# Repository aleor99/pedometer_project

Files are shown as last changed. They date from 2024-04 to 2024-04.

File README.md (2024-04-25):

# **FINAL ASSIGNMENT**

## **Electronic Technologies and Sensors Laboratory (Prof. Cerveri Pietro)**

**Students**:

Simone Lambiase

Miriam Morelli

Alessandro Ortu

**Tutor**:
Luca Marsilio

### **Description**

In this project, we designed and developed a wearable system that measures physical activity parameters from the 3-axis accelerometer LIS3DH.

The main objectives of this system are:

- Acquire data from the accelerometer using built-in FIFO to reduce the load of the CPU.
- Process and calibrate the raw data in order to obtain steps, calories, distance and speed.
- Provide a Graphical-User-Interface (GUI) where data can be displayed in real-time.
- Add some features to GUI and Hardware in order to make it more interactive and customizable.

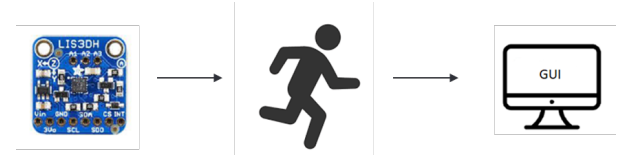
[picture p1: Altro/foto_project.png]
Semplice schematico del funzionamento


### **Requirements**

**Version**: *PSoC Creator 4.4*

**Board**: *PSoC 5LP CY8C5888LTI-LP097 in QFN68 format* [PSoC Creator](https://www.infineon.com/cms/en/design-support/tools/sdk/psoc-software/psoc-creator/)

**Additional Hardware**:

1. LIS3DH breakout board [LIS3DH Datasheet](https://www.st.com/resource/en/datasheet/lis3dh.pdf)
1. Bluetooth HC-06 [HC-06 Datasheet](https://www.st.com/resource/en/datasheet/lis3dh.pdf)
1. SSD1306 OLED by Adafruit [Adafruit Oled](https://www.adafruit.com/product/326)
1. Two external LEDs (Red and Green)
1. Button (Reset)
1. One LM7805 and two Capacitors in order to reduce the voltage from a 9 V battery to 5 V
1. One 9V battery
1. Three Resistors (two for the leds and one for the button)
2. Switch (ON/OFF)

(as an alternative to steps 6,7 and 9 , a powerbank can be used)

Additional softwares tools: Cool Term, Bridge Control Panel

## **Hardware**
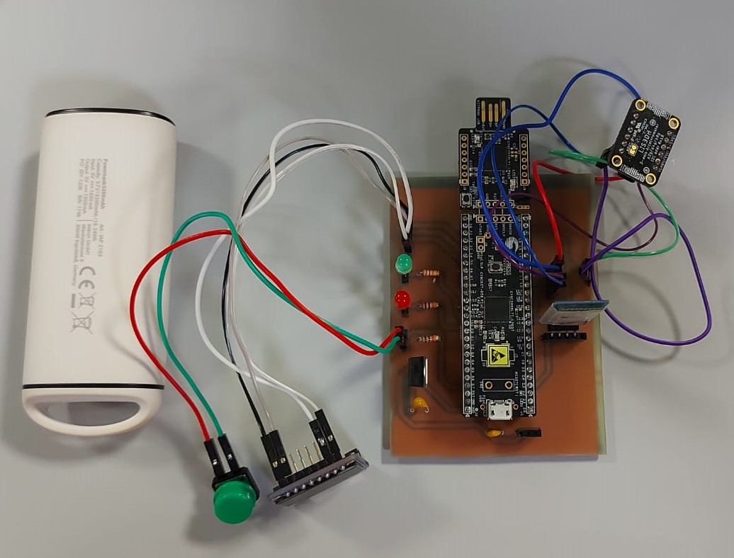
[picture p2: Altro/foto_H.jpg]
Foto Hardware

## **System Configuration**
Switch on the device via the switch (or alternatively connect the powerbank to the PSoC), check that the OLED turns on and that the Bluetooth starts flashing rapidly indicating that the device is ready to be connected. Connect the device to the PC via Bluetooth by selecting the HC-06 device and entering the password 1234. Once connected open the interface and follow the following steps:
1. Select your profile by going to "User Page", in the upper bar where you find "Search User" select your first and last name, click Load and then Save. Alternatively, register via the "Click here to register" button and then click "Save".
2. Select "Data Analysis", on this page you can view the data from the PSoC. Click "Search" and wait for the green text saying "Device found" to appear, then click "Run" to start the monitoring activity. At the bottom you will be able to see information about your physical activity, which are also shown on the OLED mounted on the device (you can switch from a parameter to the other by pressing the button on the device). At the end of monitoring, click the "Disconnect" button to disconnect.
3. In order to view and manage your data, go to "Database", on this page you can search for a user by name and by double-clicking on a row in the table, you will be able to see graphs of activity trends over time. You can also export your data to a .csv file by clicking on "Export Data".

***Additional Features***

There are two additional buttons:
- *Question mark button*: this page allows you to request help in using the interface or report possible errors. All required information must be entered and then click Send Request. 
- *Info Button*: this page shows information about the project and is the homepage of the GUI.

All operations performed on the GUI will be accompanied by warnings confirming the operation performed or helping to perform the desired operation. It is also possible to reduce the sidebar by clicking on the three lines on the left-hand side of the top bar.

### **Repository Organisation**
In the GUI FINALE folder you can find all the files necessary for the GUI, in particular:
- "Interfaccia_finale": contains the core code relating to the operation of the interface.
- "database_conn": contains the functions for connecting to the database via sqlite3.
- "dati_utenti.db": is the database (you can use DB Browser(SQLite) to open it).
- "icone_rc": contains the icons used in the interface.
- "nuova.ui": file containing the interface graphics.
- "costanti": a separate file with all the constants used.

In the PSOC folder there are all files pertaining to the PSoC firmware (divided in 2 versions, one where only the steps are shown on the OLED, the other with all the parameters, both working) and in the PC finale folder all files pertaining to the PCB.
Also, the case folder is divided in 2 folders: one for the case with the battery and one for the case with the powerbank.
Finally, in the "Altro" folder there are some old codes if you find them useful.

### **References**
- [PubMed link 1](https://pubmed.ncbi.nlm.nih.gov/25749552/)
- [PubMed link 2](https://pubmed.ncbi.nlm.nih.gov/24656871/)
- [Paper by Neil Zhao](https://www.analog.com/media/en/technical-documentation/technical-articles/pedometer.pdf)
- Course Notes by Pietro Cerveri

### **Final Presentation**
Link to the powerpoint final presentation and the videos of the demo: https://polimi365-my.sharepoint.com/:f:/g/personal/10675266_polimi_it/Ek28DVU131dCtsj3aeqviJQB96iRDbKKIaKprMv0jeDfnw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

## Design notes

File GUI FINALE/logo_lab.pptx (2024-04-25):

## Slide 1

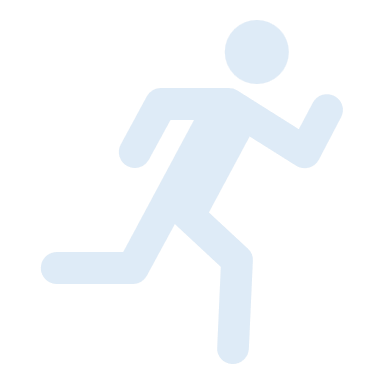
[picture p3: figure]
Eseguire con riempimento a tinta unita

Runner

Monitor, Measure, Improve

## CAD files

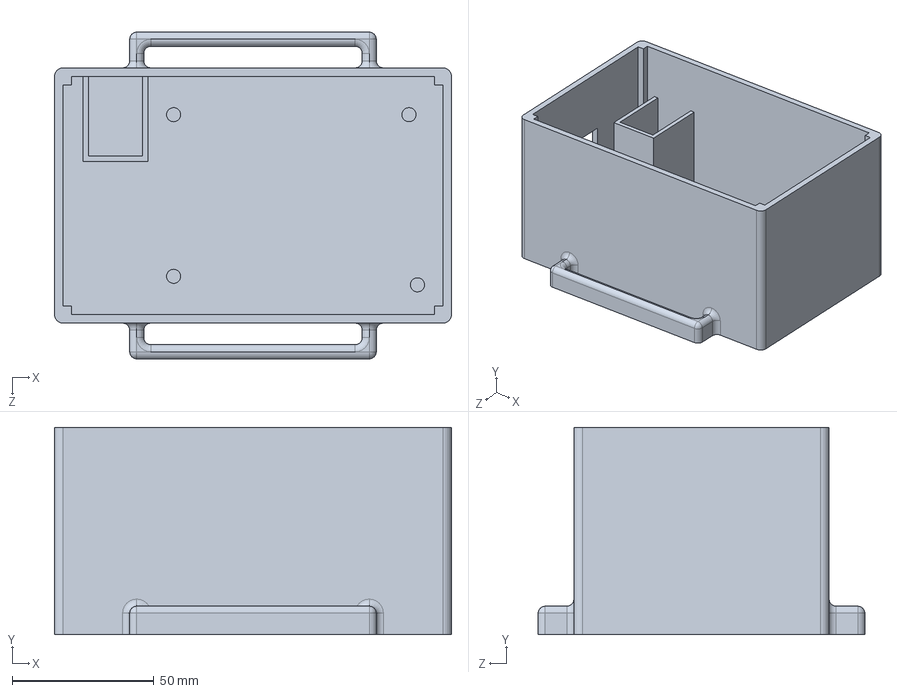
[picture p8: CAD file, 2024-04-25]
Case/Case_Batteria/Case_Batteria.SLDPRT
140.0 x 73.0 x 115.2 mm

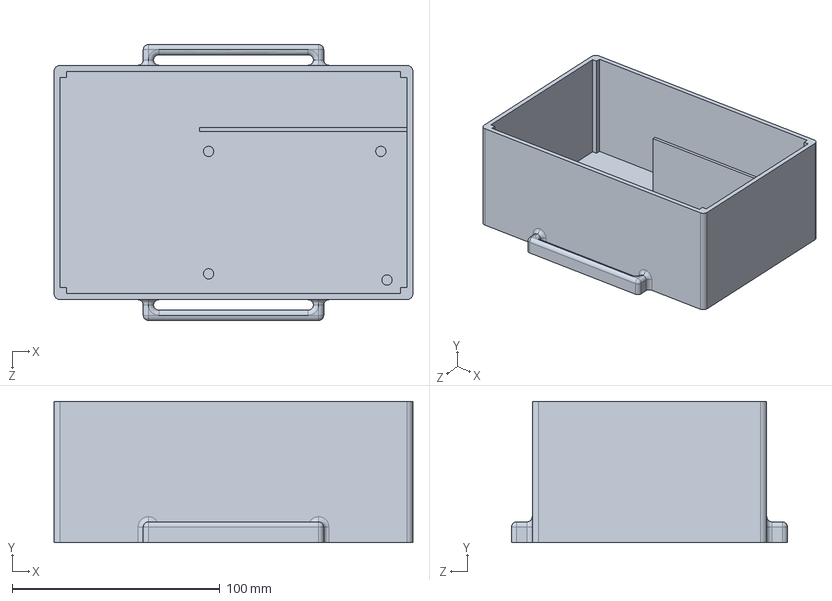
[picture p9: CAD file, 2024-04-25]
Case/Case_Powerbank/Case_Powerbank.SLDPRT
173.0 x 68.0 x 133.0 mm

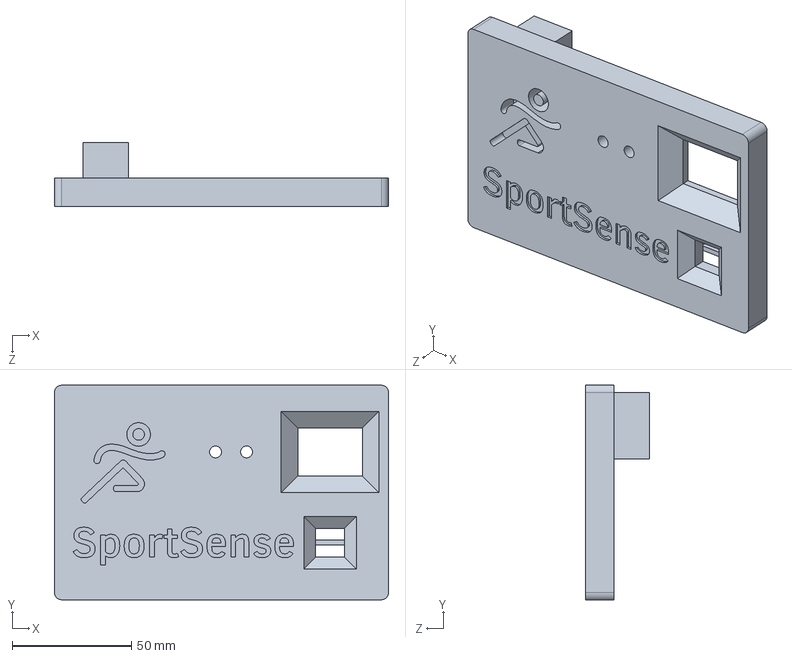
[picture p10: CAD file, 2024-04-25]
Case/Case_Batteria/Coperchio_Batteria.SLDPRT
140.0 x 90.0 x 27.0 mm

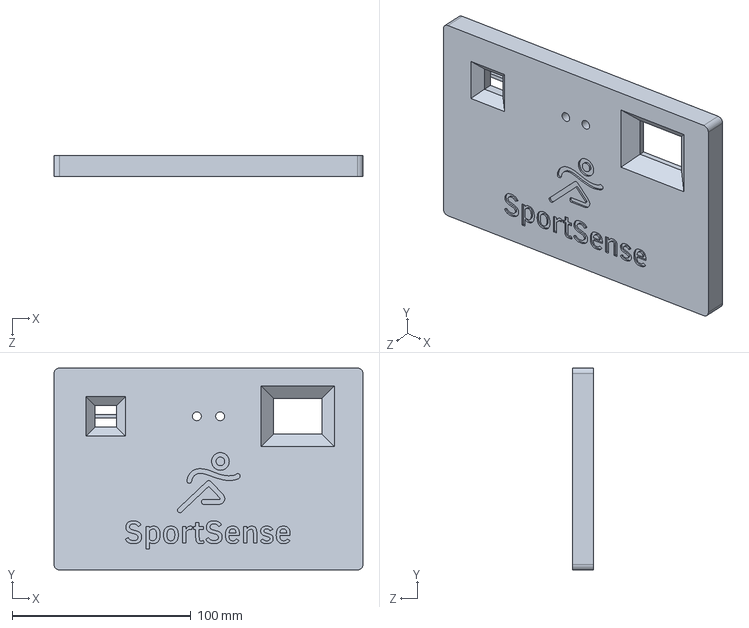
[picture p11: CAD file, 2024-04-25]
Case/Case_Powerbank/Coperchio_Powerbank.SLDPRT
173.0 x 113.0 x 12.0 mm

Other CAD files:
Case/Case_Batteria/Case_Batteria.STL
Case/Case_Batteria/Coperchio_Batteria.STL
Case/Case_Powerbank/Case_Powerbank.STL
Case/Case_Powerbank/Coperchio_Powerbank.STL

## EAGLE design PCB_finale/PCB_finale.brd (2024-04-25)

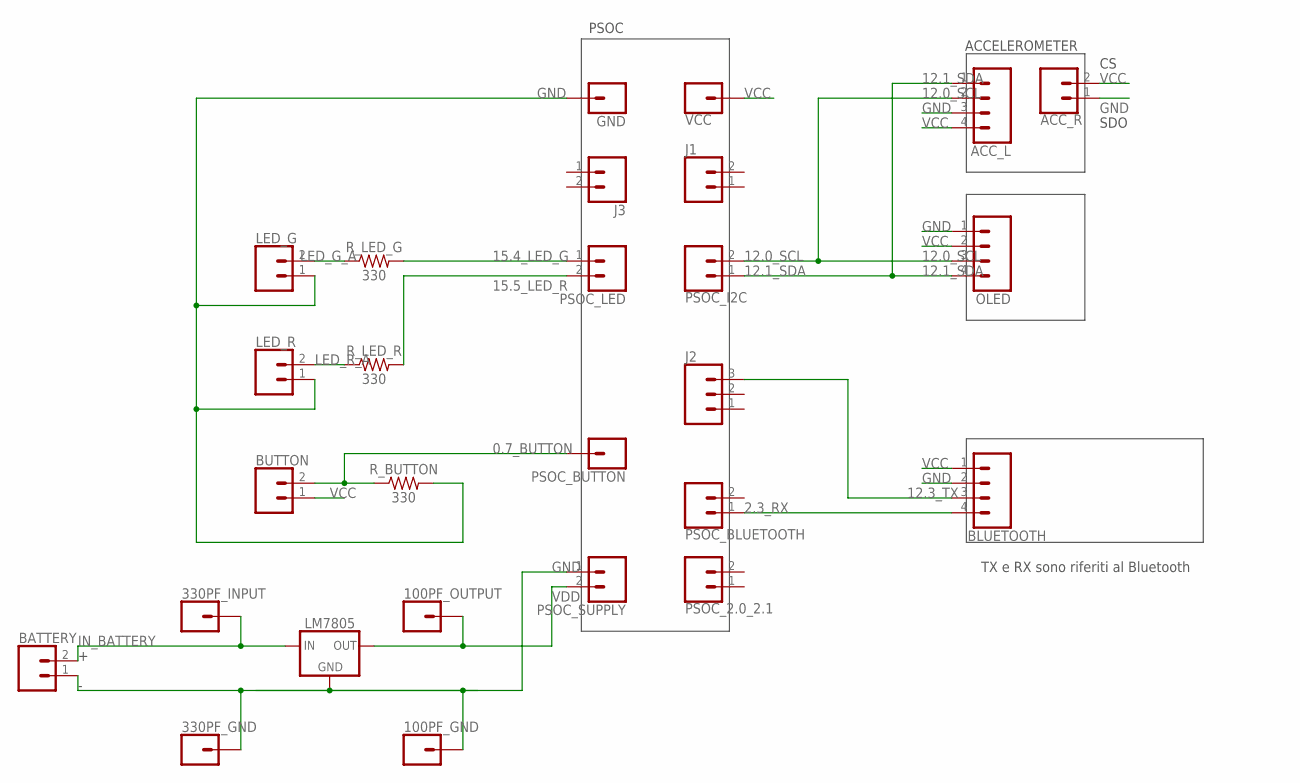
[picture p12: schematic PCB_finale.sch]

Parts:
100PF_GND, 100PF_OUTPUT, 330PF_GND, 330PF_INPUT: CONN_01; 1X01
ACC_L: CONN_04PTH; 1X04
ACC_R: CONN_02; 1X02
BATTERY: CONN_02; 1X02
BLUETOOTH: CONN_04PTH; 1X04
BUTTON: CONN_02; 1X02
GND: CONN_01; 1X01
J1, J3: CONN_02; 1X02
J2: 455-1750-1-ND; 1X03
LED_G: CONN_02; 1X02
LED_R: CONN_02; 1X02
LM7805: R-78E5.0-1.0; DC-DC_CONVERTER_78XX
OLED: CONN_04PTH; 1X04
PSOC_2.0_2.1: CONN_02; 1X02
PSOC_BLUETOOTH: CONN_02; 1X02
PSOC_BUTTON: CONN_01; 1X01
PSOC_I2C: CONN_02; 1X02
PSOC_LED: CONN_02; 1X02
PSOC_SUPPLY: CONN_02; 1X02
R_BUTTON: 330; AXIAL-0.3
R_LED_G: 330; AXIAL-0.3
R_LED_R: 330; AXIAL-0.3
VCC: CONN_01; 1X01

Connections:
0.7_BUTTON: BUTTON.2, PSOC_BUTTON.1, R_BUTTON.P$1 (1)
2.3_RX: BLUETOOTH.4, PSOC_BLUETOOTH.1
12.0_SCL: ACC_L.2, OLED.3, PSOC_I2C.2
12.1_SDA: ACC_L.1, OLED.4, PSOC_I2C.1
12.3_TX: BLUETOOTH.3, J2.3
15.4_LED_G: PSOC_LED.1, R_LED_G.P$2 (2)
15.5_LED_R: PSOC_LED.2, R_LED_R.P$2 (2)
GND: 100PF_GND.1, 330PF_GND.1, ACC_L.3, ACC_R.1, BATTERY.1, BLUETOOTH.2, GND.1, LED_G.1, LED_R.1, LM7805.GND, OLED.1, PSOC_SUPPLY.1, R_BUTTON.P$2 (2)
IN_BATTERY: 330PF_INPUT.1, BATTERY.2, LM7805.VIN (IN)
LED_G_A: LED_G.2, R_LED_G.P$1 (1)
LED_R_A: LED_R.2, R_LED_R.P$1 (1)
VCC: ACC_L.4, ACC_R.2, BLUETOOTH.1, BUTTON.1, OLED.2, VCC.1
VDD: 100PF_OUTPUT.1, LM7805.VOUT (OUT), PSOC_SUPPLY.2

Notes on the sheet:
PSOC
ACCELEROMETER
SDO
TX e RX sono riferiti al Bluetooth

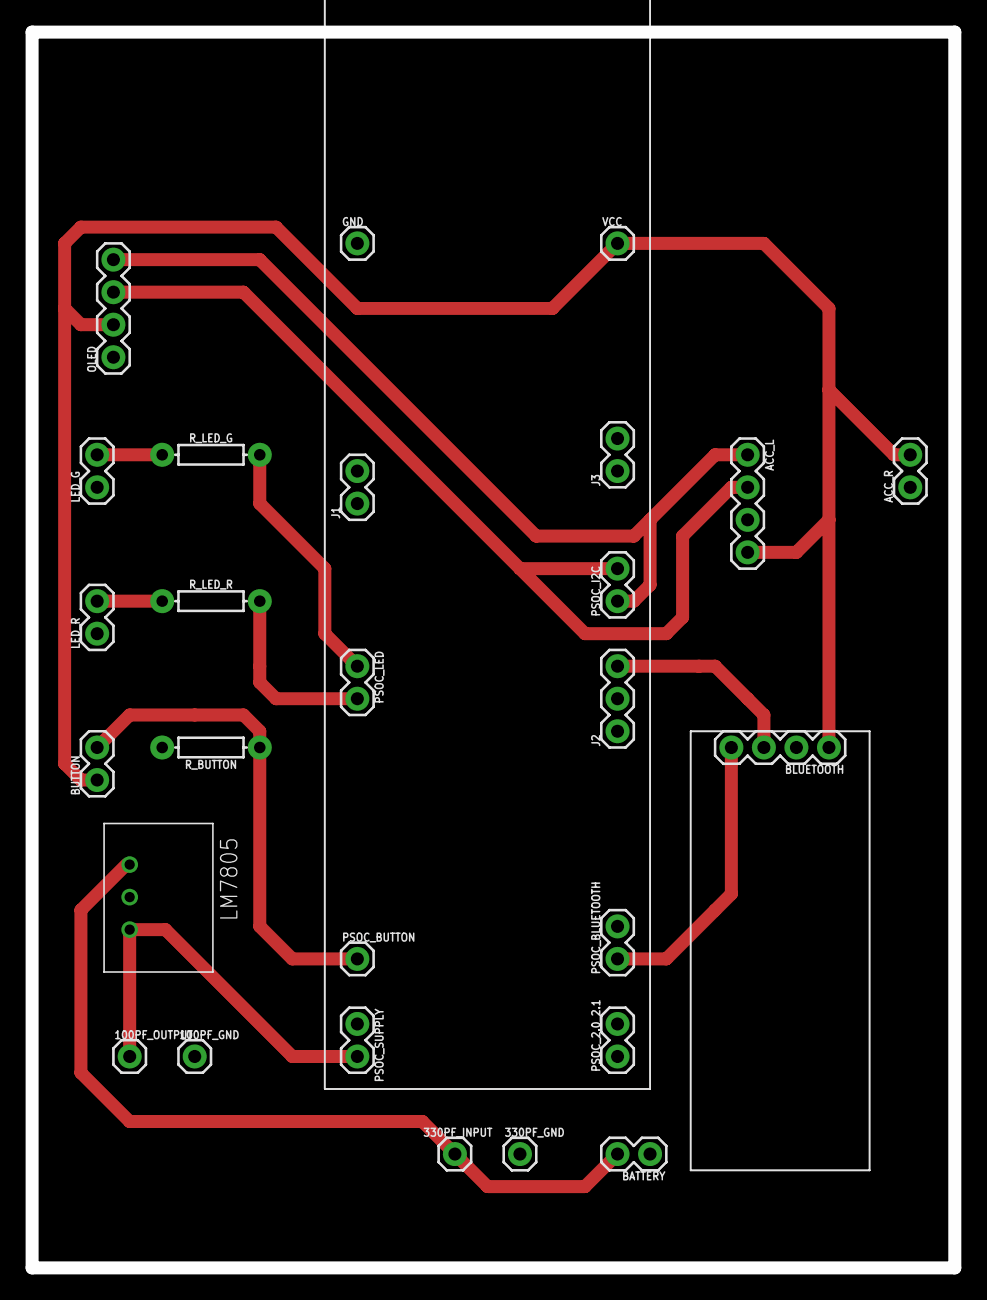
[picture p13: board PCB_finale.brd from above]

Board: 2 copper layers, 72.1 x 96.5 mm, 27 parts (0 on the bottom side), 13 nets.

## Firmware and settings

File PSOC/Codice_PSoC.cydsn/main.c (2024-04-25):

/* ========================================
 *
 * Copyright YOUR COMPANY, THE YEAR
 * All Rights Reserved
 * UNPUBLISHED, LICENSED SOFTWARE.
 *
 * CONFIDENTIAL AND PROPRIETARY INFORMATION
 * WHICH IS THE PROPERTY OF your company.
 *
 * ========================================
*/

//** libraries **//
#include <stdio.h>
#include "project.h"
#include "I2C_Interface.h"
#include "LIS3DH.h"
#include "InterruptRoutines.h"
#include "isr_RX.h"
#include "ssd1306.h"
#include "logo.h"
#include <stdlib.h>

//** define **//
#define ON 1
#define OFF 0   //controllare se li usiamo 
#define DISPLAY_ADDRESS 0x3D
#define DISPLAYWIDTH 128
#define DISPLAYHEIGHT 64

char message[50] = {'\0'};
char cal[3] ="cal";
char metri[5]=" m";
char ms[4]=" m/s";
int agg=11;
char acapo[2]="\n";


int main(void)
{
    CyGlobalIntEnable; /* Enable global interrupts. */
    
    //**Inizializations**//
    I2C_Peripheral_Start();
    display_init(DISPLAY_ADDRESS);
    UART_1_Start();
    PWM_LED_ACC_Start();
    
    //**Power up graphics**// 
    int16_t j;
    for( j = 0 ; j < gfx_height() ; j += 2 ){
            gfx_drawCircle( gfx_width()/2, gfx_height()/2, j, WHITE );
            display_update();    
        }    

    CyDelay(3000);
    
    display_clear();    
    display_update(); 
    
    CyDelay(5);
    display_clear();    
    display_update();    
    gfx_setTextSize(2);
    gfx_setTextColor(WHITE);
    gfx_setCursor(2,2);
    gfx_println("Hey there!");
    display_update();


    
    
    //**Check if LIS3DH is connected**//    
    uint32_t rval = I2C_Master_MasterSendStart(LIS3DH_DEVICE_ADDRESS, I2C_Master_WRITE_XFER_MODE);
    if( rval == I2C_Master_MSTR_NO_ERROR ) {
    }
    I2C_Master_MasterSendStop();
    
  
	//UART_1_PutString("\n\n");
    
    /******************************************/
    /*            I2C Reading                 */
    /******************************************/
          
    //**I2C Master Read - WHOAMI Register **//
    uint8_t whoami_reg;
    ErrorCode error = I2C_Peripheral_ReadRegister(LIS3DH_DEVICE_ADDRESS, 
                                                  LIS3DH_WHO_AM_I_REG_ADDR,
                                                  &whoami_reg);
    if( error == ERROR ) {
        Pin_LED_CMT_Write(ON);
    }
    //if the comunication is not correct, so if the accelerometer register is not red correctly 
    //the LED is switched on 
        

    
    //**I2C Master Read - CTRL Register 1 **//
        
    /*       control_reg1: 0x47           */
    /*         ODR[3:0]-->0100            */
    /*      LPen-->DefaultValue:0         */
    /*   Zen,Yen,Xen-->DefaultValue:1     */
    
    
    uint8_t control_reg;
    error = I2C_Peripheral_ReadRegister(LIS3DH_DEVICE_ADDRESS, 
                                        LIS3DH_CTRL_REG1,
                                        &control_reg);
    control_reg |= 0x47; // sampling 50Hz
    error = I2C_Peripheral_WriteRegister(LIS3DH_DEVICE_ADDRESS,
                                         LIS3DH_CTRL_REG1,
                                         control_reg);                  
    
    //*   I2C Temperature CTRL REG 4 Writing from LIS3DH   **//
    /*       control_reg2: 0x80               */
    /*              BDU-->1                   */
    /*        BLE-->DefaultValue:0            */
    /*       FS-->DefaultValue:00             */
    /*        HR-->DefaultValue:0             */
    /*      ST[1:0]-->DefaultValue:00         */
    /*        SIM-->DefaultValue:0            */
    
    uint8_t ctrl_reg4; // Ctrl Register variable
    error = I2C_Peripheral_ReadRegister(LIS3DH_DEVICE_ADDRESS,
                                        LIS3DH_CTRL_REG4,
                                        &ctrl_reg4);
    
    ctrl_reg4 |= LIS3DH_CTRL_REG4_BDU_ACTIVE; // must be changed to the appropriate value
    error = I2C_Peripheral_WriteRegister(LIS3DH_DEVICE_ADDRESS,
                                         LIS3DH_CTRL_REG4,
                                         ctrl_reg4);
    //* SETTING DEL FIFO *//
    
    /////////* ctrl_reg5: 0x40 */////////
    /*   BOOT --> Default value:0      */
    /*   FIFO_EN --> 1                 */
    /*   LIR_INT1 --> Default value: 0 */
    /*   D4D_INT1 --> Default value: 0 */
    /*   LIR_INT2 --> Default value: 0 */
    /*   D4D_INT2 --> Default value: 0 */
    
    uint8_t ctrl_reg5; // Ctrl Register variable
    
    error = I2C_Peripheral_ReadRegister(LIS3DH_DEVICE_ADDRESS,
                                        LIS3DH_CTRL_REG5,
                                        &ctrl_reg5);
    ctrl_reg5 |= 0x40; // enable del FIFO
    error = I2C_Peripheral_WriteRegister(LIS3DH_DEVICE_ADDRESS,
                                         LIS3DH_CTRL_REG5,
                                         ctrl_reg5); 
    
    
    //* FIFO_CTRL_REG: 0x40 *//
        
    /*      FM[1:0] --> 01 (FIFO mode)     */
    /*       TR --> Default value: 0       */
    /*   FTH[4:0] --> Default value: 0000  */
    
    uint8_t FIFO_ctrl_reg;
    
    error = I2C_Peripheral_ReadRegister(LIS3DH_DEVICE_ADDRESS,
                                        LIS3DH_FIFO_CTRL_REG,
                                        &FIFO_ctrl_reg);
    
    FIFO_ctrl_reg |= 0x40; //FIFO mode (FM = 01)
    error = I2C_Peripheral_WriteRegister(LIS3DH_DEVICE_ADDRESS,
                                         LIS3DH_FIFO_CTRL_REG,
                                         FIFO_ctrl_reg); 
    
        
    //Accelerations
    uint8_t AccData[2]; //for the two register in which are contained the 10 bits 
    int16_t OutAcc;
    
    uint8_t FIFO_src_reg; 
    uint8_t FIFO_overrun; 
    //uint8_t FIFO_unread_samples;
    
    uint8_t i=0;
    uint8_t accelerazioni_multi[192];
    uint8_t flag_ci=OFF;

    
    //**Starting of interrupts**//
    isr_RX_StartEx(Custom_ISR_RX);
    isr_BUTTON_StartEx(Custom_ISR_BUTTON);
    isr_Timer_StartEx(Custom_ISR_Timer);
    Timer_Start();
    
    for(;;)
    {
        if(Connessione_porta)
        {
            sprintf(message, "h ");
            UART_1_PutString(message);
            Connessione_porta=0;        
        }
        //When, from the GUI, the signal arrives to start the data reading 
        if (Invio_dati)
        {
            //Check FIFO overrun --> once is full teh reading starts
            error = I2C_Peripheral_ReadRegister(LIS3DH_DEVICE_ADDRESS,
                                                  LIS3DH_FIFO_SRC_REG,
                                                    &FIFO_src_reg);
            if((error!=NO_ERROR)&(flag_ci==OFF))
            {
                    Pin_LED_CMT_Write(ON);                   
                    flag_ci=ON;        
            }
            else if(error==NO_ERROR)
            {
                FIFO_overrun = FIFO_src_reg & 0x40; 
                if(FIFO_overrun == 0x40)
                {
                    flag_ci=OFF;                    
                    Pin_LED_CMT_Write(OFF);                    
                    //Reading of the data 
                    error = I2C_Peripheral_ReadRegisterMulti(LIS3DH_DEVICE_ADDRESS,
                                                             LIS3DH_OUT_ACCX_L,
                                                             192,
                                                             accelerazioni_multi);

                    //Single accelerations' computation
                    for(i=0; i<32; i++)
                    {
                        if(error == NO_ERROR)
                        {
                            //Acceleration along x axis: positions  0-1, 6-7, 12-13, ...
                            AccData[0]=accelerazioni_multi[6*i];   
                            AccData[1]=accelerazioni_multi[6*i+1];
                            OutAcc = (int16) (AccData[0] | (AccData[1] << 8)) >> 6;
                            OutAcc=(OutAcc*4);
                            sprintf(message, "Accx Output: %d mg\r\n", OutAcc);
                            UART_1_PutString(message);
                            
                            //Acceleration along y axis: positions 2-3, 8-9, 14-15, ...
                            AccData[0]=accelerazioni_multi[6*i+2];
                            AccData[1]=accelerazioni_multi[6*i+3];
                            OutAcc = (int16) (AccData[0] | (AccData[1] << 8)) >> 6;
                            OutAcc=(OutAcc*4);
                            sprintf(message, "Accy Output: %d mg \r\n", OutAcc);
                            UART_1_PutString(message);
                            
                            //Acceleration along z axis: positions 4-5, 10-11, 16-17, ...
                            AccData[0]=accelerazioni_multi[6*i+4];
                            AccData[1]=accelerazioni_multi[6*i+5];
                            OutAcc = (int16) (AccData[0] | (AccData[1] << 8)) >> 6;
                            OutAcc=(OutAcc*4);
                            sprintf(message, "Accz Output: %d mg\r\n", OutAcc);
                            UART_1_PutString(message);                            
                        }
                    }
                    
                    //FIFO's reset
                    FIFO_ctrl_reg &= 0x00; //Bypass mode
                    error = I2C_Peripheral_WriteRegister(LIS3DH_DEVICE_ADDRESS,
                                                         LIS3DH_FIFO_CTRL_REG,
                                                         FIFO_ctrl_reg); 
                    CyDelay(100);
                    
                    FIFO_ctrl_reg |= 0x40; //FIFO mode (FM = 01)
                    error = I2C_Peripheral_WriteRegister(LIS3DH_DEVICE_ADDRESS,
                                                         LIS3DH_FIFO_CTRL_REG,
                                                         FIFO_ctrl_reg);   
                    CyDelay(50);
                    
                    if(backup_s==ON)//print of the steps, made in the main for the interference between 
                                    //OLED and accelerometer                    
                    {
                        sprintf(message,"Steps: %lu",steps);
                        display_clear();    
                        display_update();    
                        gfx_setTextSize(2);
                        gfx_setTextColor(WHITE);
                        gfx_setCursor(2,2);
                        gfx_print(message);
                        display_update();  
                    }              
                    if (backup_v==ON)
                    {        
                        if(invio_OLED)
                        {
                          velocity[0]='\n';       
                          char vel_cor[BUFFER_SIZE]="Velocity: \n";
                          strcat(vel_cor,acapo);
                          for(uint i=0; i<strlen(velocity);i++)
                          {
                             if ((velocity[i]=='1') || (velocity[i]=='2')|| (velocity[i]=='3')|| (velocity[i]=='4')|| (velocity[i]=='5')|| (velocity[i]=='6')|| (velocity[i]=='7')|| (velocity[i]=='8')|| (velocity[i]=='9')|| (velocity[i]=='0'))
                            {
                                vel_cor[agg++]=velocity[i];
                            }
                          }
                          agg=11;
                          strcat(vel_cor,ms);
                          display_clear();    
                          display_update();    
                          gfx_setTextSize(2);
                          gfx_setTextColor(WHITE);
                          gfx_setCursor(2,2);
                          gfx_println(vel_cor);
                          display_update();   
                          flag_v=OFF;
                          invio_OLED=OFF;
                        }
                    }
                    if (backup_d==ON)
                    {        
                        if(invio_OLED)
                        {
                          distance[0]='\n';       
                          char dis_cor[BUFFER_SIZE]="Distance: \n";
                          strcat(dis_cor,acapo);
                          for(uint i=0; i<strlen(distance);i++)
                          {
                             if ((distance[i]=='1') || (distance[i]=='2')|| (distance[i]=='3')|| (distance[i]=='4')|| (distance[i]=='5')|| (distance[i]=='6')|| (distance[i]=='7')|| (distance[i]=='8')|| (distance[i]=='9')|| (distance[i]=='0'))
                            {
                                dis_cor[agg++]=distance[i];
                            }
                          }
                          agg=11;
                          strcat(dis_cor,metri);
                          display_clear();    
                          display_update();    
                          gfx_setTextSize(2);
                          gfx_setTextColor(WHITE);
                          gfx_setCursor(2,2);
                          gfx_println(dis_cor);
                          display_update();   
                          flag_d=OFF;
                          invio_OLED=OFF;
                        }
                    }
                    if (backup_k==ON)
                    {        
                        if(invio_OLED)
                        {
                          calories[0]='\n';       
                          char cal_cor[BUFFER_SIZE]="Calories: \n";
                          strcat(cal_cor,acapo);
                          for(uint i=0; i<strlen(calories);i++)
                          {
                             if ((calories[i]=='1') || (calories[i]=='2')|| (calories[i]=='3')|| (calories[i]=='4')|| (calories[i]=='5')|| (calories[i]=='6')|| (calories[i]=='7')|| (calories[i]=='8')|| (calories[i]=='9')|| (calories[i]=='0'))
                            {
                                cal_cor[agg++]=calories[i];
                            }
                          }  
                          agg=11; 
                          strcat(cal_cor,cal);
                          display_clear();    
                          display_update();    
                          gfx_setTextSize(2);
                          gfx_setTextColor(WHITE);
                          gfx_setCursor(2,2);
                          gfx_println(cal_cor);
                          display_update();   
                          flag_k=OFF;
                          invio_OLED=OFF;
                        }
                    }
                }
            }
        }
    }
}
/* [] END OF FILE */

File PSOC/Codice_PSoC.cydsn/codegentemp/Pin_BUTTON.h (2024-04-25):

/*******************************************************************************
* File Name: Pin_BUTTON.h  
* Version 2.20
*
* Description:
*  This file contains Pin function prototypes and register defines
*
* Note:
*
********************************************************************************
* Copyright 2008-2015, Cypress Semiconductor Corporation.  All rights reserved.
* You may use this file only in accordance with the license, terms, conditions, 
* disclaimers, and limitations in the end user license agreement accompanying 
* the software package with which this file was provided.
*******************************************************************************/

#if !defined(CY_PINS_Pin_BUTTON_H) /* Pins Pin_BUTTON_H */
#define CY_PINS_Pin_BUTTON_H

#include "cytypes.h"
#include "cyfitter.h"
#include "cypins.h"
#include "Pin_BUTTON_aliases.h"

/* APIs are not generated for P15[7:6] */
#if !(CY_PSOC5A &&\
	 Pin_BUTTON__PORT == 15 && ((Pin_BUTTON__MASK & 0xC0) != 0))


/***************************************
*        Function Prototypes             
***************************************/    

/**
* \addtogroup group_general
* @{
*/
void    Pin_BUTTON_Write(uint8 value);
void    Pin_BUTTON_SetDriveMode(uint8 mode);
uint8   Pin_BUTTON_ReadDataReg(void);
uint8   Pin_BUTTON_Read(void);
void    Pin_BUTTON_SetInterruptMode(uint16 position, uint16 mode);
uint8   Pin_BUTTON_ClearInterrupt(void);
/** @} general */

/***************************************
*           API Constants        
***************************************/
/**
* \addtogroup group_constants
* @{
*/
    /** \addtogroup driveMode Drive mode constants
     * \brief Constants to be passed as "mode" parameter in the Pin_BUTTON_SetDriveMode() function.
     *  @{
     */
        #define Pin_BUTTON_DM_ALG_HIZ         PIN_DM_ALG_HIZ
        #define Pin_BUTTON_DM_DIG_HIZ         PIN_DM_DIG_HIZ
        #define Pin_BUTTON_DM_RES_UP          PIN_DM_RES_UP
        #define Pin_BUTTON_DM_RES_DWN         PIN_DM_RES_DWN
        #define Pin_BUTTON_DM_OD_LO           PIN_DM_OD_LO
        #define Pin_BUTTON_DM_OD_HI           PIN_DM_OD_HI
        #define Pin_BUTTON_DM_STRONG          PIN_DM_STRONG
        #define Pin_BUTTON_DM_RES_UPDWN       PIN_DM_RES_UPDWN
    /** @} driveMode */
/** @} group_constants */
    
/* Digital Port Constants */
#define Pin_BUTTON_MASK               Pin_BUTTON__MASK
#define Pin_BUTTON_SHIFT              Pin_BUTTON__SHIFT
#define Pin_BUTTON_WIDTH              1u

/* Interrupt constants */
#if defined(Pin_BUTTON__INTSTAT)
/**
* \addtogroup group_constants
* @{
*/
    /** \addtogroup intrMode Interrupt constants
     * \brief Constants to be passed as "mode" parameter in Pin_BUTTON_SetInterruptMode() function.
     *  @{
     */
        #define Pin_BUTTON_INTR_NONE      (uint16)(0x0000u)
        #define Pin_BUTTON_INTR_RISING    (uint16)(0x0001u)
        #define Pin_BUTTON_INTR_FALLING   (uint16)(0x0002u)
        #define Pin_BUTTON_INTR_BOTH      (uint16)(0x0003u) 
    /** @} intrMode */
/** @} group_constants */

    #define Pin_BUTTON_INTR_MASK      (0x01u) 
#endif /* (Pin_BUTTON__INTSTAT) */


/***************************************
*             Registers        
***************************************/

/* Main Port Registers */
/* Pin State */
#define Pin_BUTTON_PS                     (* (reg8 *) Pin_BUTTON__PS)
/* Data Register */
#define Pin_BUTTON_DR                     (* (reg8 *) Pin_BUTTON__DR)
/* Port Number */
#define Pin_BUTTON_PRT_NUM                (* (reg8 *) Pin_BUTTON__PRT) 
/* Connect to Analog Globals */                                                  
#define Pin_BUTTON_AG                     (* (reg8 *) Pin_BUTTON__AG)                       
/* Analog MUX bux enable */
#define Pin_BUTTON_AMUX                   (* (reg8 *) Pin_BUTTON__AMUX) 
/* Bidirectional Enable */                                                        
#define Pin_BUTTON_BIE                    (* (reg8 *) Pin_BUTTON__BIE)
/* Bit-mask for Aliased Register Access */
#define Pin_BUTTON_BIT_MASK               (* (reg8 *) Pin_BUTTON__BIT_MASK)
/* Bypass Enable */
#define Pin_BUTTON_BYP                    (* (reg8 *) Pin_BUTTON__BYP)
/* Port wide control signals */                                                   
#define Pin_BUTTON_CTL                    (* (reg8 *) Pin_BUTTON__CTL)
/* Drive Modes */
#define Pin_BUTTON_DM0                    (* (reg8 *) Pin_BUTTON__DM0) 
#define Pin_BUTTON_DM1                    (* (reg8 *) Pin_BUTTON__DM1)
#define Pin_BUTTON_DM2                    (* (reg8 *) Pin_BUTTON__DM2) 
/* Input Buffer Disable Override */
#define Pin_BUTTON_INP_DIS                (* (reg8 *) Pin_BUTTON__INP_DIS)
/* LCD Common or Segment Drive */
#define Pin_BUTTON_LCD_COM_SEG            (* (reg8 *) Pin_BUTTON__LCD_COM_SEG)
/* Enable Segment LCD */
#define Pin_BUTTON_LCD_EN                 (* (reg8 *) Pin_BUTTON__LCD_EN)
/* Slew Rate Control */
#define Pin_BUTTON_SLW                    (* (reg8 *) Pin_BUTTON__SLW)
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

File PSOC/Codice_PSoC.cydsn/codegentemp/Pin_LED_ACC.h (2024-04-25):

/*******************************************************************************
* File Name: Pin_LED_ACC.h  
* Version 2.20
*
* Description:
*  This file contains Pin function prototypes and register defines
*
* Note:
*
********************************************************************************
* Copyright 2008-2015, Cypress Semiconductor Corporation.  All rights reserved.
* You may use this file only in accordance with the license, terms, conditions, 
* disclaimers, and limitations in the end user license agreement accompanying 
* the software package with which this file was provided.
*******************************************************************************/

#if !defined(CY_PINS_Pin_LED_ACC_H) /* Pins Pin_LED_ACC_H */
#define CY_PINS_Pin_LED_ACC_H

#include "cytypes.h"
#include "cyfitter.h"
#include "cypins.h"
#include "Pin_LED_ACC_aliases.h"

/* APIs are not generated for P15[7:6] */
#if !(CY_PSOC5A &&\
	 Pin_LED_ACC__PORT == 15 && ((Pin_LED_ACC__MASK & 0xC0) != 0))


/***************************************
*        Function Prototypes             
***************************************/    

/**
* \addtogroup group_general
* @{
*/
void    Pin_LED_ACC_Write(uint8 value);
void    Pin_LED_ACC_SetDriveMode(uint8 mode);
uint8   Pin_LED_ACC_ReadDataReg(void);
uint8   Pin_LED_ACC_Read(void);
void    Pin_LED_ACC_SetInterruptMode(uint16 position, uint16 mode);
uint8   Pin_LED_ACC_ClearInterrupt(void);
/** @} general */

/***************************************
*           API Constants        
***************************************/
/**
* \addtogroup group_constants
* @{
*/
    /** \addtogroup driveMode Drive mode constants
     * \brief Constants to be passed as "mode" parameter in the Pin_LED_ACC_SetDriveMode() function.
     *  @{
     */
        #define Pin_LED_ACC_DM_ALG_HIZ         PIN_DM_ALG_HIZ
        #define Pin_LED_ACC_DM_DIG_HIZ         PIN_DM_DIG_HIZ
        #define Pin_LED_ACC_DM_RES_UP          PIN_DM_RES_UP
        #define Pin_LED_ACC_DM_RES_DWN         PIN_DM_RES_DWN
        #define Pin_LED_ACC_DM_OD_LO           PIN_DM_OD_LO
        #define Pin_LED_ACC_DM_OD_HI           PIN_DM_OD_HI
        #define Pin_LED_ACC_DM_STRONG          PIN_DM_STRONG
        #define Pin_LED_ACC_DM_RES_UPDWN       PIN_DM_RES_UPDWN
    /** @} driveMode */
/** @} group_constants */
    
/* Digital Port Constants */
#define Pin_LED_ACC_MASK               Pin_LED_ACC__MASK
#define Pin_LED_ACC_SHIFT              Pin_LED_ACC__SHIFT
#define Pin_LED_ACC_WIDTH              1u

/* Interrupt constants */
#if defined(Pin_LED_ACC__INTSTAT)
/**
* \addtogroup group_constants
* @{
*/
    /** \addtogroup intrMode Interrupt constants
     * \brief Constants to be passed as "mode" parameter in Pin_LED_ACC_SetInterruptMode() function.
     *  @{
     */
        #define Pin_LED_ACC_INTR_NONE      (uint16)(0x0000u)
        #define Pin_LED_ACC_INTR_RISING    (uint16)(0x0001u)
        #define Pin_LED_ACC_INTR_FALLING   (uint16)(0x0002u)
        #define Pin_LED_ACC_INTR_BOTH      (uint16)(0x0003u) 
    /** @} intrMode */
/** @} group_constants */

    #define Pin_LED_ACC_INTR_MASK      (0x01u) 
#endif /* (Pin_LED_ACC__INTSTAT) */


/***************************************
*             Registers        
***************************************/
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

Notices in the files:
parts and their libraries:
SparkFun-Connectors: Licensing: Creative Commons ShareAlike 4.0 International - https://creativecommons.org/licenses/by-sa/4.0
